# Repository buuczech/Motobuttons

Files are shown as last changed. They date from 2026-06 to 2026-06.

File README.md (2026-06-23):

# OsmAnd Moto Keypad (XIAO nRF52840)

A handlebar-mounted **Bluetooth LE HID keyboard** for controlling
[OsmAnd](https://osmand.net/) navigation on Android while riding. Built around
a Seeed Studio **XIAO nRF52840**, it exposes a small set of physical buttons as
HID keystrokes (zoom, pan, etc.), with key mappings that are **remappable over
BLE from a companion Android app** and firmware that updates **over-the-air
(OTA DFU)** — no cable, no removing the device from the bike.

> Status: active hobby project. Firmware and app evolve together.

\---

## Features

* **BLE HID keyboard** — pairs with Android as a standard keyboard; OsmAnd reacts
to the configured keys.
* **3 physical buttons**, each with **short / double / long** press, all sending
configurable HID keys.
* **Remote key remapping** — assign keys from the Android app over a BLE
characteristic; mappings persist in on-chip flash.
* **App-configurable settings** — e.g. `restartOnDisconnect` (auto re-advertise
after disconnect) is toggled from the app and persisted to flash.
* **OTA firmware updates** via the Adafruit nRF52 bootloader (Nordic DFU).
* **Soft-reset gesture** — hold both outer buttons for 3 s to cleanly reboot the
MCU, with an LED countdown.
* **Status LED** on an external pin with distinct states (advertising / connected
/ reset-arming / boot).
* **Compile-time TEST / PROD modes** — strip serial logging and debug LEDs from
production builds with a single flag.
* **Optional 5-way analog joystick** (voltage-divider on an ADC pin), behind a
compile flag so an unconnected, floating pin can't generate phantom presses.

\---

## Hardware

|Part|Notes|
|-|-|
|MCU|Seeed Studio XIAO nRF52840|
|Buttons|3 momentary, active-LOW, internal pull-ups (pins D0/D1/D2)|
|Status LED|External LED on D3 and/or D4 (active-HIGH in firmware)|
|Joystick (optional)|5-way, via voltage divider into an analog pin|
|Power|USB-C or 12V from the bike|

> The on-board RGB LED is not visible inside the enclosure on the target build,
> so the firmware drives an external LED. A `TEST\_MODE` build also mirrors status
> onto the built-in LED for bench testing.

\---

## Firmware

### Toolchain

* **Arduino IDE** (or arduino-cli) with **Seeed XIAO nRF52840** board support
(the Seeed nRF52 Boards package, based on the Adafruit nRF52 / Bluefruit core).
* The two custom libraries in `firmware/libraries/` (`MyBfButton`,
`MyBfButtonManager`) — modified from
[ButtonFever](https://github.com/mickey9801/ButtonFever) by Mickey Chan.

### Build / flash

1. Select board **Seeed XIAO nRF52840**.
2. Set the compile flags at the top of `osmand\_keypad.ino` (see below).
3. First flash via USB. Subsequent updates can go **OTA** (see *OTA updates*).

### Compile-time flags

|Flag|Default|Effect|
|-|-|-|
|`TEST\_MODE`|`1`|`1` = dev: serial console on, status mirrored to the built-in LED, BLE name `"Test Osmand Keyboard"`. `0` = production: no serial, no built-in LED, BLE name `"Osmand Keyboard"`.|
|`USE\_ANALOG`|`0`|`1` = read the 5-way joystick. `0` = analog code is compiled out entirely (safe when the joystick is not wired and the pin floats).|

Derived from `TEST\_MODE`: `ENABLE\_SERIAL` and `MIRROR\_BUILTIN\_LED`. All serial
output routes through `DBG\_\*` macros that expand to nothing in a production
build.

### Status LED states

|State|Pattern|
|-|-|
|Boot|three quick flashes (also confirms a reset completed)|
|Advertising / disconnected|slow \~500 ms blink|
|Connected|solid on|
|Reset arming|blink that accelerates over 3 s, then a rapid strobe before reboot|

### Soft-reset gesture

Hold **both outer buttons** (Dbtn1 + Dbtn3) for **3 s** → clean `NVIC\_SystemReset()`.
While the combo is held, normal key sending is suppressed so the gesture doesn't
emit stray keystrokes.

\---

## BLE protocol

Custom configuration service (alongside the standard HID, Device Information,
and DFU services):

* **Service UUID:** `12345678-1234-5678-1234-56789abcdef0`

### Key-mapping characteristic — `...def1` (Write, fixed 9 bytes)

Each button gets 3 bytes: `{ single, double, long }`. Values are **USB HID usage
IDs** (the `HID\_KEY\_\*` constants); `0x00` = no action.

> \*\*Important ordering gotcha.\*\* The firmware indexes the array as
> `customKeys\[getID() \* 3]`, and on this library `getID()` returns the \*\*pin
> number\*\*, not the construction order. The real byte → button mapping is:

|Bytes|Button|Pin|
|-|-|-|
|0–2|Dbtn3|0|
|3–5|Dbtn2|1|
|6–8|Dbtn1|2|

The Android app must send bytes in this order (`data\[0]` → Dbtn3).

### Settings characteristic — `...def2` (Write, fixed `SETTINGS\_LEN` bytes)

|Index|Setting|Values|
|-|-|-|
|0|`restartOnDisconnect`|`0x00` = false (default), `0x01` = true|

Writes are persisted to flash and applied live (no reboot needed). The length is
fixed, so when settings grow, bump `SETTINGS\_LEN` and update both sides together.

\---

## OTA updates

Firmware updates over BLE use the Adafruit nRF52 bootloader (Nordic legacy DFU).
The recommended Android path is the official
[Nordic Android DFU Library](https://github.com/NordicSemiconductor/Android-DFU-Library).

**Known issue — bonded GATT cache.** Because the device is an HID keyboard it is
bonded, and Android caches its services. The Adafruit bootloader keeps the same
MAC address in DFU mode, so the first OTA attempt can fail with
`GATT INVALID\_HANDLE` and succeed on retry. Practical mitigations (all app-side):

* `setNumberOfRetries(2..3)` on the `DfuServiceInitiator` (automates the retry
that already works).
* Keep the same address for legacy DFU (do **not** force-scan for `address+1`).
* Force a GATT cache refresh before connecting if needed.

See `docs/ble-protocol.md` and the project notes for details.

\---

## Android app

The companion app (in `android/`) handles:

* Pairing and connecting as the HID host.
* Reading/writing the key-mapping and settings characteristics.
* Triggering and running OTA DFU.

\---

## Credits \& license

* Firmware uses **Adafruit Bluefruit nRF52** (Adafruit / Nordic).
* `MyBfButton` / `MyBfButtonManager` are derived from **ButtonFever** by
Mickey Chan, MIT-licensed.

This project is released under the [MIT License](LICENSE) unless noted otherwise
in a subfolder. Third-party components keep their own licenses.

\---

*Built by BuuCzech Development.*

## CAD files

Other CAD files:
hardware/Exports/Joystick_v1.step
hardware/Exports/MotoButtons_v2.step
hardware/Exports/MotoButtons_v1.step

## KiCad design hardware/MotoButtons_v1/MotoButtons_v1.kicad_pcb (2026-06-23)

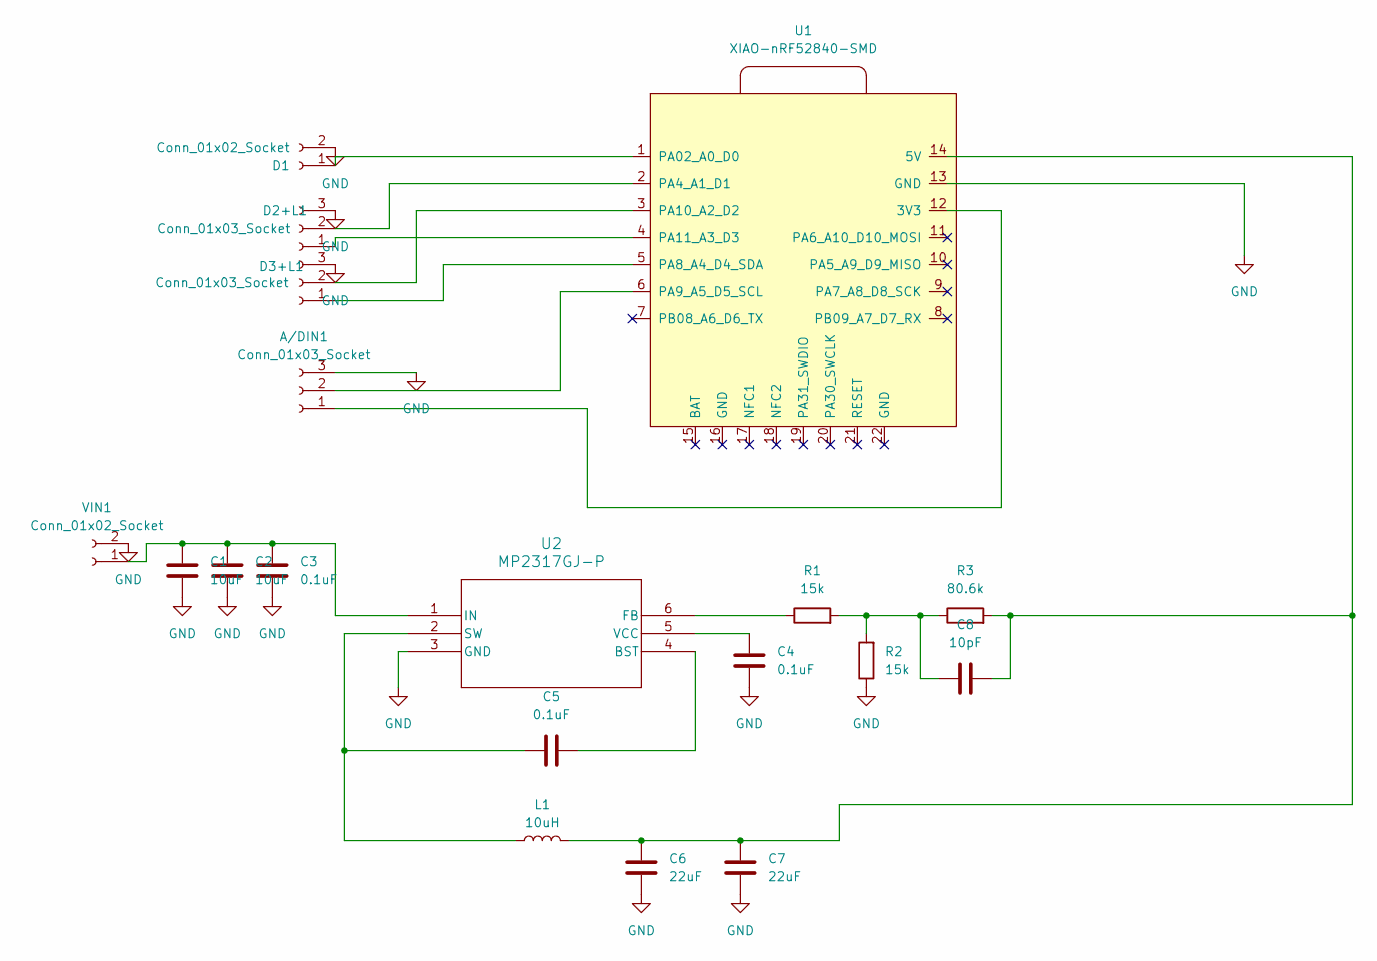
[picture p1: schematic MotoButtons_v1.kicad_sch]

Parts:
A/DIN1: Conn_01x03_Socket; Molex_SMD_3pin_2035560307
C1, C2: 10uF; C_0603_1608Metric_Pad1.08x0.95mm_HandSolder
C3, C4, C5: 0.1uF; C_0603_1608Metric_Pad1.08x0.95mm_HandSolder
C6, C7: 22uF; C_0603_1608Metric_Pad1.08x0.95mm_HandSolder
C8: 10pF; C_0603_1608Metric_Pad1.08x0.95mm_HandSolder
D1: Conn_01x02_Socket; Molex_SMD_2Pin_2035560207
D2+L1, D3+L1: Conn_01x03_Socket; Molex_SMD_3pin_2035560307
L1: 10uH; L_1008_2520Metric_Pad1.43x2.20mm_HandSolder
R1, R2: 15k; R_0603_1608Metric_Pad0.98x0.95mm_HandSolder
R3: 80.6k; R_0603_1608Metric_Pad0.98x0.95mm_HandSolder
U1: XIAO-nRF52840-SMD
U2: MP2317GJ-P; TSOT23-6_MPS_MNP
VIN1: Conn_01x02_Socket; JST_PH_B2B-PH-SM4-TB_1x02-1MP_P2.00mm_Vertical

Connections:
GND: A/DIN1.3, C1.2, C2.2, C3.2, C4.2, C6.2, C7.2, D1.2, D2+L1.3, D3+L1.3, R2.1, U1.13 (GND), U2.3 (GND), VIN1.2
unnamed: A/DIN1.1, U1.12 (3V3)
unnamed: A/DIN1.2, U1.6 (PA9_A5_D5_SCL)
unnamed: C8.1, R1.2, R2.2, R3.1
unnamed: D1.1, U1.1 (PA02_A0_D0)
unnamed: D2+L1.1, U1.4 (PA11_A3_D3)
unnamed: D2+L1.2, U1.2 (PA4_A1_D1)
unnamed: D3+L1.1, U1.5 (PA8_A4_D4_SDA)
unnamed: D3+L1.2, U1.3 (PA10_A2_D2)
unnamed: C6.1, C7.1, C8.2, L1.2, R3.2, U1.14 (5V)
unnamed: C5.1, U2.4 (BST)
unnamed: R1.1, U2.6 (FB)
unnamed: C1.1, C2.1, C3.1, U2.1 (IN), VIN1.1
unnamed: C5.2, L1.1, U2.2 (SW)
unnamed: C4.1, U2.5 (VCC)

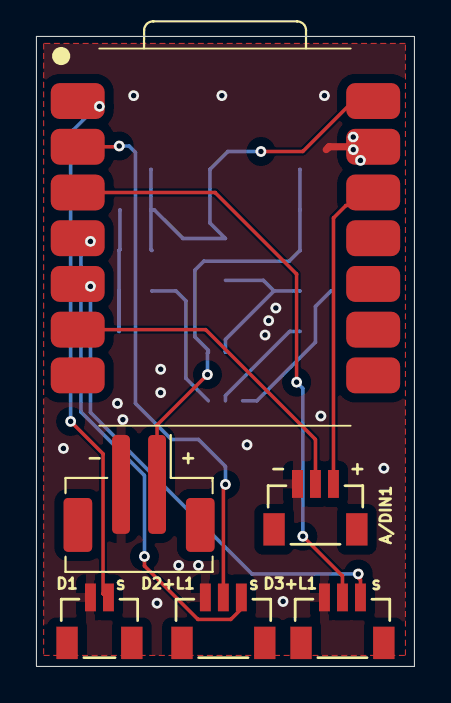
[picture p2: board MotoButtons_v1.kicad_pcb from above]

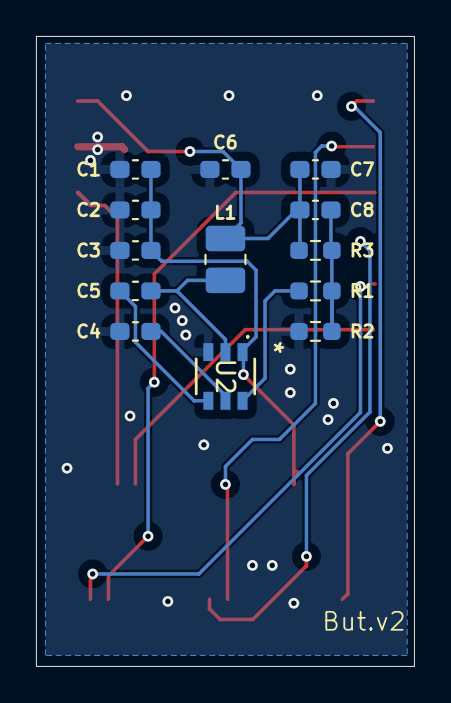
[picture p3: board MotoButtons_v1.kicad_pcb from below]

Board: 2 copper layers, 21.0 x 35.0 mm, 19 parts (13 on the bottom side), 15 nets.

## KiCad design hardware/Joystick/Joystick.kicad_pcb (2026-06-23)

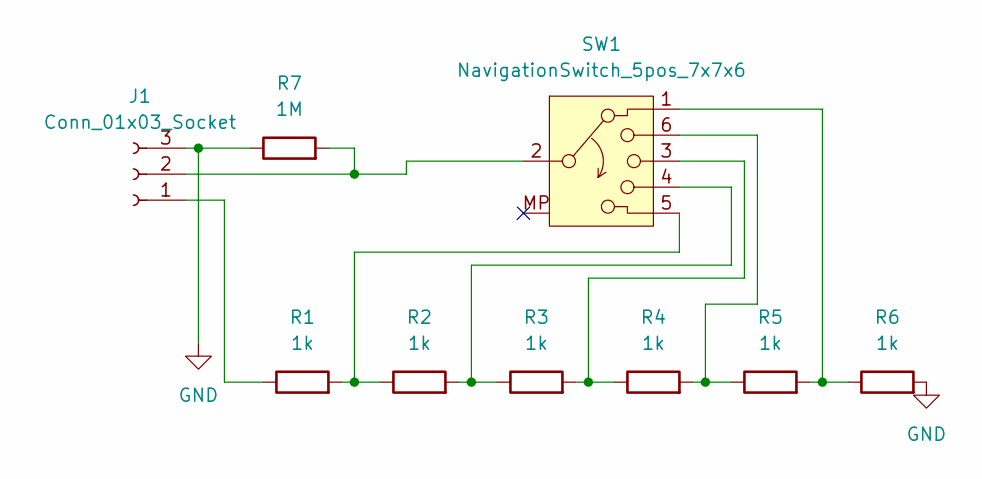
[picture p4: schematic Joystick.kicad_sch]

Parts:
J1: Conn_01x03_Socket; Molex_SMD_3pin_2035560307
R1, R2, R3, R4, R5, R6: 1k; R_0603_1608Metric_Pad0.98x0.95mm_HandSolder
R7: 1M; R_0603_1608Metric_Pad0.98x0.95mm_HandSolder
SW1: NavigationSwitch_5pos_7x7x6; Navigation Switch 7x7x6

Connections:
GND: J1.3, R6.2, R7.1
unnamed: J1.1, R1.1
unnamed: J1.2, R7.2, SW1.2
unnamed: R2.2, R3.1, SW1.4
unnamed: R3.2, R4.1, SW1.3
unnamed: R4.2, R5.1, SW1.6
unnamed: R5.2, R6.1, SW1.1
unnamed: R1.2, R2.1, SW1.5 (Push)

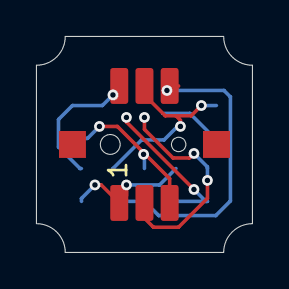
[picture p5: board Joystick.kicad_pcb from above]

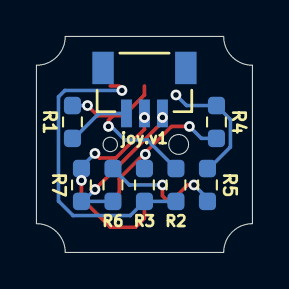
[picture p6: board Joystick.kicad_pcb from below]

Board: 2 copper layers, 12.0 x 12.0 mm, 9 parts (8 on the bottom side), 8 nets.

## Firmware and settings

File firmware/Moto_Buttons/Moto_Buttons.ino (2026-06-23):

#include <bluefruit.h>
#include <Arduino.h>
#include "src/MyBfButton.h"
#include "src/MyBfButtonManager.h"
#include <Adafruit_LittleFS.h>
#include <InternalFileSystem.h>

#define FW_VERSION "test_1.0.0"

// ==================== KONFIGURACE / COMPILE FLAGS ====================
// TEST_MODE: 1 = vývoj/testování, 0 = produkce.
//   Zapíná sériovou konzoli a zrcadlení stavu na built-in LED a používá
//   "Test" jméno zařízení. V produkci to vše vypne.
#define TEST_MODE 1

// USE_ANALOG: 1 = číst 5-směrný joystick (voltage divider na analog pinu),
//   0 = vůbec nepoužívat. Na cílovém HW joystick není a plovoucí pin jinak
//   občas generuje falešné stisky -> tehdy nech 0.
#define USE_ANALOG 0

// --- Odvozené přepínače (běžně neměnit) ---
#define MIRROR_BUILTIN_LED TEST_MODE   // built-in LED jen při testování
#define ENABLE_SERIAL      TEST_MODE   // sériová konzole jen při testování

// --- Debug makra: v produkci se přeloží do prázdna (žádný Serial v buildu) ---
#if ENABLE_SERIAL
  #define DBG_BEGIN(baud)  Serial.begin(baud)
  #define DBG_PRINT(...)   Serial.print(__VA_ARGS__)
  #define DBG_PRINTLN(...) Serial.println(__VA_ARGS__)
  #define DBG_FLUSH()      Serial.flush()
#else
  #define DBG_BEGIN(baud)
  #define DBG_PRINT(...)
  #define DBG_PRINTLN(...)
  #define DBG_FLUSH()
#endif
// ====================================================================

using namespace Adafruit_LittleFS_Namespace;
const char* CONFIG_FILENAME   = "/keypad_cfg.dat";
const char* SETTINGS_FILENAME = "/keypad_set.dat";

// --- Piny tlačítek (hodnota = číslo pinu, které vrací getID()) ---
const unsigned int D1btnPin = 2;   // Dbtn1
const unsigned int D2btnPin = 1;   // Dbtn2
const unsigned int D3btnPin = 0;   // Dbtn3

// --- Stavová LED ---
// Na cílovém HW není vidět built-in RGB LED, používá se externí modrá LED.
// Je připojená na D3 nebo D4 -> budíme obě stejně, aby to fungovalo bez ohledu
// na to, do kterého pinu je reálně zapojená.
const uint8_t STATUS_LED_A = D3;
const uint8_t STATUS_LED_B = D4;
#define LED_ON  HIGH    // pokud je LED zapojená jako active-LOW, prohoď na LOW
#define LED_OFF LOW

// Built-in LED svítí v LOW (opačná polarita než D3/D4), budíme ji invertovaně.
const uint8_t BUILTIN_STATUS_LED = LED_BLUE;   // nebo LED_BUILTIN / LED_RED / LED_GREEN

bool isConnected = false;
bool ledState = false;
unsigned long previousMillis = 0;
const long blinkInterval = 500;   // pomalé blikání při odpojení

// --- Soft reset (čistý restart MCU) ---
// Combo = oba krajní knoflíky (Dbtn1 + Dbtn3) podržené po dobu RESET_HOLD_MS.
const unsigned long RESET_HOLD_MS = 3000;
unsigned long resetComboStart = 0;
bool resetComboActive = false;

// --- Digitální tlačítka ---
MyBfButton Dbtn1(MyBfButton::STANDALONE_DIGITAL, D1btnPin, true, LOW, HID_KEY_EQUAL, HID_KEY_NONE, HID_KEY_ARROW_UP);
MyBfButton Dbtn2(MyBfButton::STANDALONE_DIGITAL, D2btnPin, true, LOW, HID_KEY_C,     HID_KEY_NONE, HID_KEY_NONE);
MyBfButton Dbtn3(MyBfButton::STANDALONE_DIGITAL, D3btnPin, true, LOW, HID_KEY_MINUS, HID_KEY_NONE, HID_KEY_ARROW_DOWN);

// --- Analogový 5-směrný joystick (jen když USE_ANALOG) ---
#if USE_ANALOG
const unsigned int AbtnPin = 5;
MyBfButtonManager manager(AbtnPin, 5);
// Směry mají pevné klávesy (nejsou přemapovatelné z appky).
MyBfButton Abtn1(MyBfButton::ANALOG_BUTTON_ARRAY, 0, true, LOW, HID_KEY_ARROW_DOWN,  HID_KEY_NONE, HID_KEY_NONE);
MyBfButton Abtn2(MyBfButton::ANALOG_BUTTON_ARRAY, 1, true, LOW, HID_KEY_ARROW_LEFT,  HID_KEY_NONE, HID_KEY_NONE);
MyBfButton Abtn3(MyBfButton::ANALOG_BUTTON_ARRAY, 2, true, LOW, HID_KEY_ARROW_RIGHT, HID_KEY_NONE, HID_KEY_NONE);
MyBfButton Abtn4(MyBfButton::ANALOG_BUTTON_ARRAY, 3, true, LOW, HID_KEY_ARROW_UP,    HID_KEY_NONE, HID_KEY_NONE);
MyBfButton Abtn5(MyBfButton::ANALOG_BUTTON_ARRAY, 4, true, LOW, HID_KEY_C,           HID_KEY_NONE, HID_KEY_NONE);
#endif

// --- BLE init ---
BLEDis bledis;
BLEHidAdafruit blehid;
BLEDfu bledfu;
BLEService        configService("12345678-1234-5678-1234-56789abcdef0");
BLECharacteristic configCharacteristic("12345678-1234-5678-1234-56789abcdef1");   // mapování kláves (9 B)
BLECharacteristic settingsCharacteristic("12345678-1234-5678-1234-56789abcdef2"); // nastavení (viz SETTINGS_LEN)

// 9 vlastních kláves v paměti: pro každé tlačítko { single, double, long }.
// POZOR: handler indexuje pole jako customKeys[getID()*3] a getID() vrací
// ČÍSLO PINU (ne pořadí konstrukce). Proto je skutečné mapování:
//   sloty 0-2 -> pin 0 = Dbtn3
//   sloty 3-5 -> pin 1 = Dbtn2
//   sloty 6-8 -> pin 2 = Dbtn1
// Pořadí bytů z Android appky musí tomuhle odpovídat (data[0] -> Dbtn3).
uint8_t customKeys[9] = {
  HID_KEY_EQUAL, HID_KEY_NONE, HID_KEY_ARROW_UP,    // Dbtn3 (pin 0): single, double, long
  HID_KEY_C,     HID_KEY_NONE, HID_KEY_NONE,        // Dbtn2 (pin 1): single, double, long
  HID_KEY_MINUS, HID_KEY_NONE, HID_KEY_ARROW_DOWN   // Dbtn1 (pin 2): single, double, long
};

// --- Nastavení konfigurovatelné z Android appky (persistované do flash) ---
// Zápisem do settingsCharacteristic (UUID ...def2). Délka musí být SETTINGS_LEN.
#define SETTINGS_LEN 1
#define SET_RESTART_ON_DISCONNECT 0   // index v poli settings[]
uint8_t settings[SETTINGS_LEN] = {
  0   // [0] restartOnDisconnect: 0 = false (výchozí), 1 = true
};

// --- Prototypy ---
void connect_callback(uint16_t conn_handle);
void disconnect_callback(uint16_t conn_handle, uint8_t reason);
void config_write_callback(uint16_t conn_hdl, BLECharacteristic* chr, uint8_t* data, uint16_t len);
void settings_write_callback(uint16_t conn_hdl, BLECharacteristic* chr, uint8_t* data, uint16_t len);
void startAdv(void);
void sendKey(uint8_t keycode);
void ledWrite(bool on);
void bootBlink(void);
void updateStatusLed(void);
bool handleResetCombo(void);
void saveSettings(void);
void loadSettings(void);
void applySettings(void);
const char* btnName(uint8_t id);

// ---- LED helpery ----
void ledWrite(bool on) {
  digitalWrite(STATUS_LED_A, on ? LED_ON : LED_OFF);
  digitalWrite(STATUS_LED_B, on ? LED_ON : LED_OFF);
#if MIRROR_BUILTIN_LED
  digitalWrite(BUILTIN_STATUS_LED, on ? LOW : HIGH);   // built-in je active-LOW
#endif
}

// Krátké trojí bliknutí = viditelné potvrzení, že firmware (znovu) naběhl.
// Slouží zároveň jako potvrzení proběhlého resetu.
void bootBlink(void) {
  for (int i = 0; i < 3; i++) {
    ledWrite(true);  delay(60);
    ledWrite(false); delay(120);
  }
}

// Stavová logika LED:
//   připojeno   -> trvale svítí
//   odpojeno    -> pomalu bliká (advertising)
//   reset combo -> řeší handleResetCombo() (zrychlující se blikání)
void updateStatusLed(void) {
  if (isConnected) {
    ledWrite(true);
    return;
  }
  unsigned long now = millis();
  if (now - previousMillis >= blinkInterval) {
    previousMillis = now;
    ledState = !ledState;
    ledWrite(ledState);
  }
}

// Pošle jednu klávesu (přeskočí prázdné NONE sloty)
void sendKey(uint8_t keycode) {
  if (keycode == HID_KEY_NONE) return;
  uint8_t report[6] = { keycode, HID_KEY_NONE, HID_KEY_NONE, HID_KEY_NONE, HID_KEY_NONE, HID_KEY_NONE };
  blehid.keyboardReport(0, report);
  delay(10);
  blehid.keyRelease();
}

// Jméno tlačítka podle getID() (= číslo pinu). Použito jen pro serial debug.
const char* btnName(uint8_t id) {
  switch (id) {
    case 2:  return "Dbtn1";
    case 1:  return "Dbtn2";
    case 0:  return "Dbtn3";
    default: return "Dbtn?";
  }
}

void DpressHandler(MyBfButton *btn, MyBfButton::press_pattern_t pattern) {
  uint8_t id = btn->getID();
  int offset = id * 3;   // viz poznámka u customKeys[]

  switch (pattern) {
    case MyBfButton::SINGLE_PRESS:
      DBG_PRINT(btnName(id)); DBG_PRINT(" SHORT  -> key 0x"); DBG_PRINTLN(customKeys[offset], HEX);
      sendKey(customKeys[offset]);
      break;

    case MyBfButton::DOUBLE_PRESS:
      DBG_PRINT(btnName(id)); DBG_PRINT(" DOUBLE -> key 0x"); DBG_PRINTLN(customKeys[offset + 1], HEX);
      sendKey(customKeys[offset + 1]);
      break;

    case MyBfButton::LONG_PRESS:
      if (!Bluefruit.connected()) {
        DBG_PRINT(btnName(id)); DBG_PRINTLN(" LONG   -> restart advertising");
        Bluefruit.Advertising.start(0);
      } else {
        DBG_PRINT(btnName(id)); DBG_PRINT(" LONG   -> key 0x"); DBG_PRINTLN(customKeys[offset + 2], HEX);
        sendKey(customKeys[offset + 2]);
      }
      break;
  }
}

#if USE_ANALOG
// Joystick posílá jen single press (pevně dané klávesy z konstruktoru).
void ApressHandler(MyBfButton *btn, MyBfButton::press_pattern_t pattern) {
  if (pattern == MyBfButton::SINGLE_PRESS) {
    DBG_PRINT("Analog dir id "); DBG_PRINT(btn->getID());
    DBG_PRINT(" -> key 0x");     DBG_PRINTLN(btn->getKeyCodeSingle(), HEX);
    sendKey(btn->getKeyCodeSingle());
  }
}
#endif

void saveConfig() {
  DBG_PRINTLN("Ukladam config do flash...");
  InternalFS.remove(CONFIG_FILENAME);   // InternalFS vyžaduje smazat soubor před zápisem

  File file = InternalFS.open(CONFIG_FILENAME, FILE_O_WRITE);
  if (file) {
    file.write(customKeys, sizeof(customKeys));
    file.close();
    DBG_PRINTLN("Config ulozen.");
  } else {
    DBG_PRINTLN("Nepodarilo se otevrit soubor pro zapis.");
  }
}

void loadConfig() {
  DBG_PRINTLN("Nacitam config z flash...");

  if (InternalFS.exists(CONFIG_FILENAME)) {
    File file = InternalFS.open(CONFIG_FILENAME, FILE_O_READ);
    if (file) {
      int bytesRead = file.read(customKeys, sizeof(customKeys));
      file.close();

      if (bytesRead == sizeof(customKeys)) {
        DBG_PRINTLN("Config nacten.");
      } else {
        DBG_PRINTLN("Nesouhlasi velikost configu!");
      }
    } else {
      DBG_PRINTLN("Nepodarilo se otevrit soubor pro cteni.");
    }
  } else {
    DBG_PRINTLN("Zadny config nenalezen, pouzivam vychozi hodnoty.");
  }
}

// --- Nastavení (settings) - stejný princip jako config ---
void saveSettings() {
  DBG_PRINTLN("Ukladam settings do flash...");
  InternalFS.remove(SETTINGS_FILENAME);

  File file = InternalFS.open(SETTINGS_FILENAME, FILE_O_WRITE);
  if (file) {
    file.write(settings, sizeof(settings));
    file.close();
    DBG_PRINTLN("Settings ulozeny.");
  } else {
    DBG_PRINTLN("Settings: zapis selhal.");
  }
}

void loadSettings() {
  DBG_PRINTLN("Nacitam settings z flash...");

  if (InternalFS.exists(SETTINGS_FILENAME)) {
    File file = InternalFS.open(SETTINGS_FILENAME, FILE_O_READ);
    if (file) {
      int bytesRead = file.read(settings, sizeof(settings));
      file.close();

      if (bytesRead == sizeof(settings)) {
        DBG_PRINTLN("Settings nacteny.");
      } else {
        DBG_PRINTLN("Nesouhlasi velikost settings!");
      }
    } else {
      DBG_PRINTLN("Settings: cteni selhalo.");
    }
  } else {
    DBG_PRINTLN("Zadne settings, pouzivam vychozi hodnoty.");
  }
}

// Aplikuje aktuální settings[] na chování zařízení (lze volat za běhu).
void applySettings() {
  bool restart = (settings[SET_RESTART_ON_DISCONNECT] != 0);
  Bluefruit.Advertising.restartOnDisconnect(restart);
  DBG_PRINT("restartOnDisconnect = "); DBG_PRINTLN(restart);
}

void setup() {
  DBG_BEGIN(115200);
  DBG_PRINTLN("Starting...");

  // Inicializace flash a načtení configu + nastavení
  InternalFS.begin();
  loadConfig();
  loadSettings();

  // --- Stavová LED ---
  pinMode(STATUS_LED_A, OUTPUT);
  pinMode(STATUS_LED_B, OUTPUT);
#if MIRROR_BUILTIN_LED
  pinMode(BUILTIN_STATUS_LED, OUTPUT);
#endif
  ledWrite(false);

  // Piny digitálních tlačítek nastavuje knihovna (INPUT_PULLUP, protože
  // pullup=true), takže přímé digitalRead() v reset combu je spolehlivé.
  Dbtn1.onPress(DpressHandler); Dbtn1.onDoublePress(DpressHandler); Dbtn1.onPressFor(DpressHandler, 1000);
  Dbtn2.onPress(DpressHandler); Dbtn2.onDoublePress(DpressHandler); Dbtn2.onPressFor(DpressHandler, 1000);
  Dbtn3.onPress(DpressHandler); Dbtn3.onDoublePress(DpressHandler); Dbtn3.onPressFor(DpressHandler, 1000);

#if USE_ANALOG
  // Joystick: jen onPress (snappy odezva; double/long stejně nevyužíváme).
  manager.setADCResolution(1024);
  Abtn1.onPress(ApressHandler); manager.addButton(&Abtn1, 140, 165);
  Abtn2.onPress(ApressHandler); manager.addButton(&Abtn2, 280, 330);
  Abtn3.onPress(ApressHandler); manager.addButton(&Abtn3, 450, 480);
  Abtn4.onPress(ApressHandler); manager.addButton(&Abtn4, 600, 640);
  Abtn5.onPress(ApressHandler); manager.addButton(&Abtn5, 750, 800);
  manager.begin();
#endif

  // --- BLE start ---
  Bluefruit.begin();
  //Bluefruit.Security.setPIN("123456");
  //Bluefruit.Security.setMITM(true);

  configService.begin();

  // Charakteristika pro mapování kláves (9 bytů)
  configCharacteristic.setProperties(CHR_PROPS_WRITE);
  configCharacteristic.setPermission(SECMODE_OPEN, SECMODE_OPEN);
  configCharacteristic.setFixedLen(9);   // 3 tlačítka * 3 události = 9 bytů
  configCharacteristic.setWriteCallback(config_write_callback);
  configCharacteristic.begin();

  // Charakteristika pro nastavení (SETTINGS_LEN bytů)
  settingsCharacteristic.setProperties(CHR_PROPS_WRITE);
  settingsCharacteristic.setPermission(SECMODE_OPEN, SECMODE_OPEN);
  settingsCharacteristic.setFixedLen(SETTINGS_LEN);
  settingsCharacteristic.setWriteCallback(settings_write_callback);
  settingsCharacteristic.begin();

  Bluefruit.Periph.setConnectCallback(connect_callback);
  Bluefruit.Periph.setDisconnectCallback(disconnect_callback);

  Bluefruit.setTxPower(8);
#if TEST_MODE
  Bluefruit.setName("Test Osmand Keyboard");
#else
  Bluefruit.setName("Osmand Keyboard");
#endif

  bledis.setManufacturer("BuuCzech Development");
  bledis.setModel("MotoButtons (XIAO nRF52840) fw " FW_VERSION);
  DBG_PRINT("Firmware "); DBG_PRINTLN(FW_VERSION);
  bledis.begin();
  blehid.begin();
  bledfu.begin();   // OTA - potřeba i v produkci

  // --- Bonding podle verze knihovny ---
  #if ARDUINO_NRF52_ADAFRUIT_VERSION_MAJOR >= 1
    BluefruitBonds.begin();
  #endif

  startAdv();

  bootBlink();   // viditelné potvrzení (re)startu firmwaru
}

void startAdv(void) {
  Bluefruit.Advertising.addFlags(BLE_GAP_ADV_FLAGS_LE_ONLY_GENERAL_DISC_MODE);
  Bluefruit.Advertising.addTxPower();
  Bluefruit.Advertising.addAppearance(BLE_APPEARANCE_HID_KEYBOARD);

  Bluefruit.Advertising.addService(blehid);
  Bluefruit.Advertising.addService(bledfu);
  Bluefruit.Advertising.addService(configService);
  Bluefruit.Advertising.addName();

  // restartOnDisconnect je nastavitelný z Android appky (settings[0]).
  // false = po odpojení se advertising NEspustí sám (znovu až dlouhým stiskem);
  // true  = zařízení se samo zase nabízí k připojení.
  applySettings();

  Bluefruit.Advertising.setInterval(32, 244);
  Bluefruit.Advertising.setFastTimeout(30);
  Bluefruit.Advertising.start(0);
}

// --- Callbacky ---
void connect_callback(uint16_t conn_handle) {
  (void) conn_handle;
  isConnected = true;
  ledWrite(true);
  DBG_PRINTLN("Pripojeno");
}

void disconnect_callback(uint16_t conn_handle, uint8_t reason) {
  (void) conn_handle;
  (void) reason;
  isConnected = false;
  previousMillis = 0;   // ať blikání naběhne hned
  DBG_PRINTLN("Odpojeno");
}

void config_write_callback(uint16_t conn_hdl, BLECharacteristic* chr, uint8_t* data, uint16_t len) {
  if (len == 9) {
    DBG_PRINTLN("Prijata nova konfigurace klaves z Androidu!");
    for (int i = 0; i < 9; i++) {
      customKeys[i] = data[i];
    }
    saveConfig();
  }
}

void settings_write_callback(uint16_t conn_hdl, BLECharacteristic* chr, uint8_t* data, uint16_t len) {
  if (len == SETTINGS_LEN) {
    DBG_PRINTLN("Prijata nova nastaveni z Androidu!");
    for (int i = 0; i < SETTINGS_LEN; i++) {
      settings[i] = data[i];
    }
    saveSettings();
    applySettings();   // aplikovat hned za běhu (není nutný restart)
  }
}

// --- Soft reset combo ---
// Vrací true, pokud combo právě probíhá (pak loop přeskočí normální čtení
// tlačítek, aby se během reset gesta neodeslaly žádné klávesy).
bool handleResetCombo(void) {
  // tlačítka jsou aktivní v LOW
  bool comboHeld = (digitalRead(D1btnPin) == LOW) && (digitalRead(D3btnPin) == LOW);

  if (!comboHeld) {
    if (resetComboActive) {
      resetComboActive = false;
      ledWrite(false);   // zhasnout indikátor (stavová logika ho hned přepíše)
    }
    return false;
  }

  if (!resetComboActive) {
    resetComboActive = true;
    resetComboStart = millis();
  }

  unsigned long held = millis() - resetComboStart;

  if (held >= RESET_HOLD_MS) {
    DBG_PRINTLN("Reset combo - restartuji...");
    DBG_FLUSH();
    for (int i = 0; i < 10; i++) {   // rychlý záblesk = potvrzení
      ledWrite(i % 2 == 0);
      delay(50);
    }
    ledWrite(false);
    NVIC_SystemReset();   // čistý restart MCU - sem se už nevrátí
  }

  // Indikátor: blikání se zrychluje, jak se blíží reset
  unsigned long blinkRate = map(held, 0, RESET_HOLD_MS, 200, 40);
  ledWrite((millis() / blinkRate) % 2 == 0);
  return true;
}

void loop() {
  // Reset combo má přednost: pokud probíhá, neřeš nic dalšího
  if (handleResetCombo()) {
    return;
  }

  Dbtn1.read();
  Dbtn2.read();
  Dbtn3.read();

#if USE_ANALOG
  manager.loop();
#endif

  updateStatusLed();
}

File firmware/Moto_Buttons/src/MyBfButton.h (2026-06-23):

/*
 * MyBfButton.h
 * Standalone digital button module handle various button events
 * Copyright (c) 2019 Mickey Chan
 *
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
 * Developed for Arduino-ESP32
 * Created by Mickey Chan (developer AT comicparty.com)
 */
#ifndef MyBfButton_h
#define MyBfButton_h

#include "bluefruit.h"
#include "Arduino.h"

class MyBfButton {
  public:
    typedef enum {
      STANDALONE_DIGITAL,
      ANALOG_BUTTON_ARRAY
    } button_mode_t;
    
    typedef enum {
      IDLE,
      PRESSING
    } button_state_t;
    
    typedef enum {
      SINGLE_PRESS,
      DOUBLE_PRESS,
      LONG_PRESS
    } press_pattern_t;
    
    typedef void (*callback_t)(MyBfButton *btn, press_pattern_t pattern);
    
    /*
     * Constructor
     * Params:
     * mode         Button mode
     * pin          Analog pin for button array
     * pullup       Determin use internal pullup on the board or external pullup/pulldown
     * buttonLogic  Determin button logic for triggering button pressed events
	 * keycode		HID character
     */
    MyBfButton(button_mode_t mode, uint8_t pin, bool pullup=true, uint8_t buttonLogic=LOW, uint8_t keyCodeSingle = HID_KEY_NONE, uint8_t keyCodeLong = HID_KEY_NONE, uint8_t keyCodeDouble = HID_KEY_NONE);
    
    /*
     * Assign event callbacks
     */
    MyBfButton& onPress(callback_t callback);
    MyBfButton& onDoublePress(callback_t callback, unsigned long timeout=300);
    MyBfButton& onPressFor(callback_t callback, unsigned long timeout=3000);
    
    /*
     * Public method for updating button object state
     */
    MyBfButton& updateState(button_state_t state);
    
    /*
     * Update button state every 20 milliseconds
     * Should be put in loop() of the sketch
     */
    void read(); // only for standalone digital button
    
    /*
     * Trigger button pressed events based on button state
     */
    void loop();
    
    /*
     * Return button pin number for digital button,
     * or ID for button in button array
     */
    uint8_t getID();
    
    /*
     * Alias of getID()
     */
    uint8_t getPin();
	
	//Alias of GetKeyCodeSingle()//
	uint8_t getKeyCodeSingle();
	
	//Alias of GetKeyCodeLong()//
	uint8_t getKeyCodeLong();
	
	//Alias of GetKeyCodeDouble()//
	uint8_t getKeyCodeDouble();
    
  private:
    // settings
    uint8_t _id;
    button_mode_t _mode;
    uint8_t _buttonLogic = LOW;
	uint8_t _keyCodeSingle = HID_KEY_NONE;
	uint8_t _keyCodeLong = HID_KEY_NONE;
	uint8_t _keyCodeDouble = HID_KEY_NONE;
    unsigned long _lastLoop = 0;
    uint8_t _loopInterval = 20;
    unsigned long _doublePressTimeout = 300; // 0.3 seconds
    unsigned long _pressForTimeout = 3000; // 3 seconds
    // runtime
    button_state_t _prevState = MyBfButton::IDLE;
    button_state_t _state = MyBfButton::IDLE;
    uint8_t _pressCount = 0;
    unsigned long _firstPressedAt = 0;
    unsigned long _pressedSince = 0;
    bool _isDebouncing = false;
    // callbacks
    callback_t _onPressCallback;
    callback_t _onDoublePressCallback;
    callback_t _onPressForCallback;
};

#endif // MyBfButton_h

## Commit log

2026-06-23 Apply .gitignore: stop tracking build artifacts and KiCad backups/caches
    [Joystick.kicad_pcb, Joystick.kicad_pcb_bom.csv, Joystick.kicad_pcb_positions.csv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]
2026-06-23 Stop tracking KiCad backup folders
2026-06-23 Stop tracking PCBWay production outputs
    [Joystick.kicad_pcb_bom.csv, Joystick.kicad_pcb_positions.csv, MotoButtons_v1.kicad_pcb_bom.csv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]
2026-06-23 added FW version info to the ino. Corrected .gitignore
    [Moto_Buttons.ino]
